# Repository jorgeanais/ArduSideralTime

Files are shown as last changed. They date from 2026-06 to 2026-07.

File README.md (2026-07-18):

# ArduSideralTime

Small project to calculate and show Local Sidereal Time (LST) on a small OLED display using Arduino.

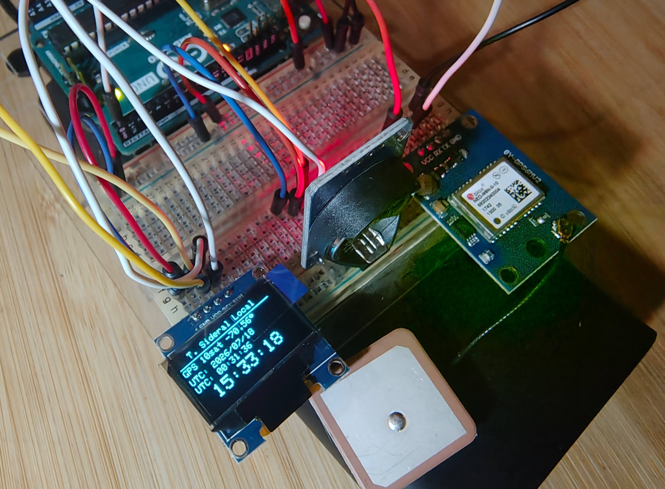
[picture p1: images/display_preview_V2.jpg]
Display Preview

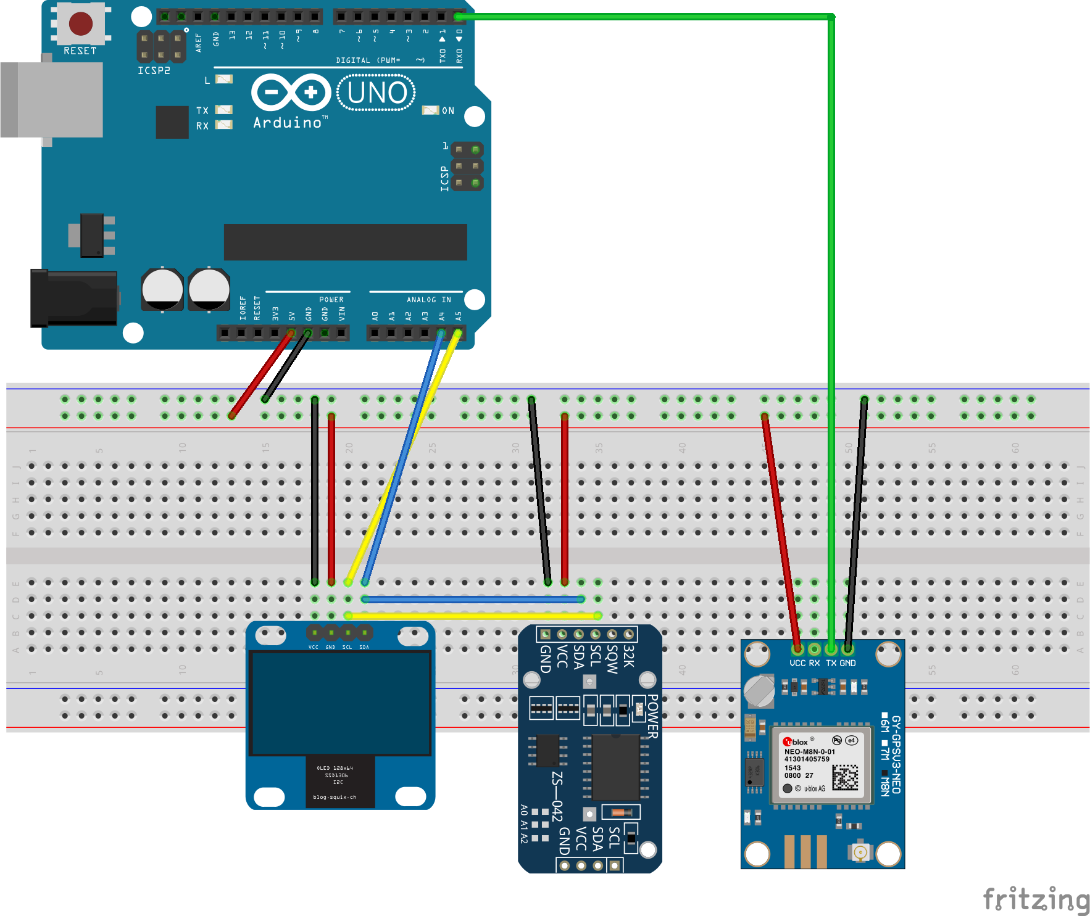
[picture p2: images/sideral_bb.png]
Circuit Diagram


## Description
This project utilizes a GPS module, a Real-Time Clock (RTC), and an OLED display to show the current UTC time and the corresponding Local Sidereal Time. The GPS synchronizes the RTC automatically with UTC time and provides real-time longitude for accurate LST calculations. The LST is calculated mathematically based on the Julian Date and the user's longitude. By default, it is configured for Santiago, Chile.

## Hardware Requirements
- Any standard Arduino-compatible board (Uno, Nano, etc.)
- SSD1306 OLED Display (128x64 resolution, I2C interface)
- DS3231 RTC Module (Real-Time Clock, I2C interface)
- NEO-M8N GPS Module (or compatible)

## Software Dependencies
You will need to install the following libraries via the Arduino Library Manager:
- `Adafruit GFX Library`
- `Adafruit SSD1306`
- `RTClib` (by Adafruit)
- `TinyGPS++` (by Mikal Hart)

## GPS Wiring Note
The GPS communicates through the Arduino's **hardware UART** (pins 0/1), not `SoftwareSerial`. This frees up enough RAM for the OLED display's buffer to allocate reliably.

**Wiring:**
- GPS TX → Arduino pin 0 (RX0)
- GPS RX → Leave unconnected (no commands are sent to the GPS)

**Important:** Pins 0/1 are shared with the USB programmer. You must **disconnect the GPS TX wire from pin 0 before uploading the sketch**, then reconnect it afterward. Leaving it connected during upload may cause the upload to fail or get corrupted.

**Recommended upload sequence:**
1. Disconnect GPS TX from pin 0
2. Upload the sketch
3. Reconnect GPS TX to pin 0
4. Power-cycle or reset the board (don't just watch — actually cycle power)
5. Check Serial Monitor and the display

## Configuration
Before uploading the sketch, you can modify the following constants in `src/sideraltime_script/sideraltime_script.ino`:

```cpp
const float LONGITUD_SANTIAGO = -70.6693; // Fallback longitude if GPS has no fix (West is negative)
const int   CORRECCION_SEG    = 0;        // Fine-tune seconds if needed
```

> **Note:** The longitude is only used as a fallback when the GPS has no fix. When the GPS has a valid fix, the sketch uses the GPS-provided longitude automatically.

## Directory Structure
- `src/`: Contains the main Arduino sketch (`.ino`).
- `fritzing/`: Circuit schematic and breadboard diagram (Fritzing files).
- `images/`: Project images and diagrams.
- `scripts/`: Directory reserved for future auxiliary scripts (e.g., Python, Bash).

## Notas en español
- La primera vez que se conecta espera 45 segundos a recibir la señal de GPS. Típicamente durante ese tiempo el módulo GPS no ha tenido suficiente tiempo para triangular una posición, por lo que el dispositivo se basará en la información por defecto de posición (SCL) y de la hora almacenada en el reloj interno.
- Cuando el módulo GPS reciba señal de suficientes satélites para hacer la triangulación, emitirá una luz intermitente roja. El sistema actualiza la hora del reloj interno a la hora recibida por GPS cada 10 minutos. Si se desea forzar la actualización de hora, presionar el botón reset en el arduino.
- Por alguna razón, no lo logré hacer funcionar en un Arduino Nano.

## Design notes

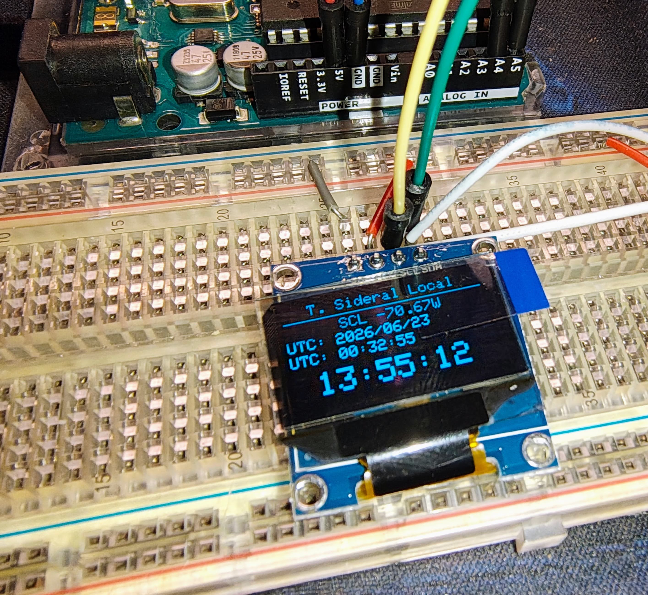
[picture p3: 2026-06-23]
images/display_preview.jpg

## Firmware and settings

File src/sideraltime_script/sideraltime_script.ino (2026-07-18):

#include <Wire.h>
#include <Adafruit_GFX.h>
#include <Adafruit_SSD1306.h>
#include <RTClib.h>
#include <TinyGPS++.h>

#define SCREEN_WIDTH 128
#define SCREEN_HEIGHT 64
#define OLED_RESET    -1

// --- GPS ---
// El Uno solo tiene UN puerto UART de hardware (pines 0/1), el mismo que
// usa el USB para el Monitor Serie y para subir sketches. Lo usamos
// tambien para el GPS en vez de SoftwareSerial: SoftwareSerial reserva su
// propio buffer + logica adicional en RAM, y en un Uno (solo 2KB de RAM)
// eso deja muy poco margen para el buffer de pantalla del SSD1306, que se
// reserva dinamicamente (malloc) al llamar display.begin(). Si ese malloc
// no encuentra espacio, falla con "SSD1306 allocation failed" -- que es
// justo el sintoma que se ve al agregar GPS con SoftwareSerial.
//
// Cableado: GPS TX -> Arduino pin RX0 (pin 0). GPS RX no se usa (no le
// enviamos comandos), puede ir sin conectar.
//
// IMPORTANTE: desconecta el cable GPS TX -> RX0 mientras subes el sketch
// (el programador usa ese mismo pin), y reconectalo despues de subir.
#define GPS_BAUD 9600

// Reintentar sincronizar el RTC con el GPS cada 10 minutos si hay fix
const unsigned long RESYNC_INTERVAL_MS = 10UL * 60UL * 1000UL;
// Tiempo maximo esperando el primer fix al encender (ms)
const unsigned long TIMEOUT_FIX_INICIAL_MS = 45000UL;

Adafruit_SSD1306 display(SCREEN_WIDTH, SCREEN_HEIGHT, &Wire, OLED_RESET);
RTC_DS3231 rtc;
TinyGPSPlus gps;

// Longitud usada si el GPS no tiene fix (oeste = negativo)
const float LONGITUD_SANTIAGO = -70.6693;
const int   CORRECCION_SEG    = 0; // ajuste fino manual si aun lo necesitas

unsigned long ultimaActualizacion = 0;
unsigned long ultimoResync = 0;
bool gpsSincronizadoAlgunaVez = false;
bool gpsFixReciente = false; // fix visto en los ultimos segundos (para UI)

float calcularLST(int anio, int mes, int dia, int hora, int minuto, int segundo, float longitud) {
  if (mes <= 2) { anio--; mes += 12; }
  int A = anio / 100;
  int B = 2 - A + A / 4;
  long JD0 = (long)(365.25 * (anio + 4716))
           + (long)(30.6001 * (mes + 1))
           + dia + B - 1524;

  long D_entero = JD0 - 2451545L;
  float D_frac  = -0.5 + (hora + minuto / 60.0 + segundo / 3600.0) / 24.0;

  float GST = 280.46061837
            + fmod(360.98564736629 * D_entero, 360.0)
            + 360.98564736629 * D_frac;

  GST = fmod(GST, 360.0);
  if (GST < 0) GST += 360.0;

  float LST = GST / 15.0 + longitud / 15.0;
  LST = fmod(LST, 24.0);
  if (LST < 0) LST += 24.0;

  return LST;
}

// Lee todo lo disponible del GPS (por el UART de hardware) y, si hay
// datos de hora/fecha frescos y validos, ajusta el RTC (que pasa a
// guardar UTC directamente). Devuelve true si el RTC fue actualizado.
bool actualizarDesdeGPS() {
  while (Serial.available() > 0) {
    gps.encode(Serial.read());
  }

  gpsFixReciente = gps.location.isValid() && gps.location.age() < 3000;

  bool horaValida  = gps.time.isValid() && gps.time.age() < 1000;
  bool fechaValida = gps.date.isValid() && gps.date.age() < 1000;

  if (horaValida && fechaValida && gps.date.year() >= 2020) {
    DateTime utcGPS(gps.date.year(), gps.date.month(), gps.date.day(),
                     gps.time.hour(), gps.time.minute(), gps.time.second());
    rtc.adjust(utcGPS);
    gpsSincronizadoAlgunaVez = true;
    return true;
  }
  return false;
}

void setup() {
  // Un solo Serial.begin: se usa tanto para el Monitor Serie (debug)
  // como para leer al GPS, ya que comparten el mismo UART de hardware.
  Serial.begin(GPS_BAUD);

  if (!display.begin(SSD1306_SWITCHCAPVCC, 0x3C)) {
    Serial.println(F("SSD1306 allocation failed"));
    for (;;);
  }

  if (!rtc.begin()) {
    Serial.println(F("Couldn't find RTC"));
    while (1);
  }

  if (rtc.lostPower()) {
    // Solo como ultimo respaldo si el RTC nunca tuvo bateria/hora.
    // Sera corregido en cuanto el GPS obtenga el primer fix.
    rtc.adjust(DateTime(F(__DATE__), F(__TIME__)));
  }

  // Buscar el primer fix GPS antes de arrancar el loop principal,
  // para partir con la hora UTC correcta desde el encendido.
  display.clearDisplay();
  display.setTextSize(1);
  display.setTextColor(SSD1306_WHITE);
  display.setCursor(0, 0);
  display.print(F("Buscando GPS..."));
  display.display();

  unsigned long inicio = millis();
  while (millis() - inicio < TIMEOUT_FIX_INICIAL_MS) {
    if (actualizarDesdeGPS()) break;

    display.clearDisplay();
    display.setCursor(0, 0);
    display.print(F("Buscando GPS..."));
    display.setCursor(0, 12);
    display.print(F("Sats: "));
    display.print(gps.satellites.isValid() ? gps.satellites.value() : 0);
    display.setCursor(0, 24);
    display.print(F("Chars: "));
    display.print(gps.charsProcessed());
    display.display();
  }

  if (!gpsSincronizadoAlgunaVez) {
    Serial.println(F("Sin fix GPS inicial, usando hora del RTC."));
    if (gps.charsProcessed() < 10) {
      Serial.println(F("Aviso: no llegan datos NMEA. Revisa el cableado TX/RX y el baudrate."));
    }
  }

  ultimoResync = millis();
  display.clearDisplay();
  display.display();
}

void loop() {
  // Alimentar el parser GPS en cada vuelta del loop (no solo 1 vez/seg).
  while (Serial.available() > 0) {
    gps.encode(Serial.read());
  }

  unsigned long ahora = millis();

  if (ahora - ultimoResync >= RESYNC_INTERVAL_MS) {
    ultimoResync = ahora;
    actualizarDesdeGPS();
  } else {
    // igual actualiza el flag de fix reciente para la UI
    gpsFixReciente = gps.location.isValid() && gps.location.age() < 3000;
  }

  if (ahora - ultimaActualizacion < 1000) return;
  ultimaActualizacion = ahora;

  // El RTC ya guarda UTC (fue sincronizado por GPS), solo se aplica
  // la correccion fina manual en segundos si el usuario la definio.
  DateTime utc = DateTime(rtc.now().unixtime() + CORRECCION_SEG);

  float longitudActual = LONGITUD_SANTIAGO;
  if (gpsFixReciente) {
    longitudActual = gps.location.lng();
  }

  float lst = calcularLST(
    utc.year(), utc.month(), utc.day(),
    utc.hour(), utc.minute(), utc.second(),
    longitudActual
  );

  int lst_h = (int)lst;
  int lst_m = (int)((lst - lst_h) * 60);
  int lst_s = (int)(((lst - lst_h) * 60 - lst_m) * 60);

  display.clearDisplay();

  // Titulo
  display.setTextSize(1);
  display.setTextColor(SSD1306_WHITE);
  display.setCursor(16, 0);
  display.print(F("T. Sideral Local"));
  display.drawLine(0, 10, 127, 10, SSD1306_WHITE);

  // Estado GPS + longitud usada
  display.setCursor(0, 13);
  if (gpsFixReciente) {
    display.print(F("GPS "));
    display.print(gps.satellites.value());
    display.print(F("sat "));
  } else {
    display.print(F("RTC  "));
  }
  display.print(longitudActual, 2);
  display.print((char)247); // grado

  // Fecha UTC
  display.setCursor(0, 25);
  display.print(F("UTC: "));
  display.print(utc.year(), DEC);
  display.print('/');
  if (utc.month() < 10) display.print('0');
  display.print(utc.month(), DEC);
  display.print('/');
  if (utc.day() < 10) display.print('0');
  display.print(utc.day(), DEC);

  // Hora UTC
  display.setCursor(0, 35);
  display.print(F("UTC: "));
  if (utc.hour() < 10) display.print('0');
  display.print(utc.hour());
  display.print(':');
  if (utc.minute() < 10) display.print('0');
  display.print(utc.minute());
  display.print(':');
  if (utc.second() < 10) display.print('0');
  display.print(utc.second());

  // LST en grande
  display.setTextSize(2);
  display.setCursor(14, 46);
  if (lst_h < 10) display.print('0');
  display.print(lst_h);
  display.print(':');
  if (lst_m < 10) display.print('0');
  display.print(lst_m);
  display.print(':');
  if (lst_s < 10) display.print('0');
  display.print(lst_s);

  display.display();
}

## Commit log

2026-06-23 feat: add initial arduino LST clock sketch
2026-06-23 feat: add fritzing schematic for the circuit
    [sideral.fzz]
2026-07-17 feat: update fritzing schematic with GPS module and OLED parts
    [sideral.fzz]
2026-07-18 docs: update README with GPS module, wiring notes, and circuit diagram
2026-07-18 feat: integrate GPS for RTC sync and dynamic longitude
    [sideral.fzz]
2026-07-18 fix: clock cables
